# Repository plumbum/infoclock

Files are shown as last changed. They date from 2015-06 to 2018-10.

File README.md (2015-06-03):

HMI WiFi board
==============

Features
--------

  * STM32F103Cxxx MCU;
  * TFT LCD 3.2" with resistive touchscreen;
  * WiFi ESP8266 based module;
  * USB device;
  * MicroSD card slot;
  * Buzzer;
  * DHT22 themperature/humidity sensor.

Library
-------

  * [ChibiOS/RT](http://www.chibios.org/)
  * [uGFX](http://ugfx.org/)

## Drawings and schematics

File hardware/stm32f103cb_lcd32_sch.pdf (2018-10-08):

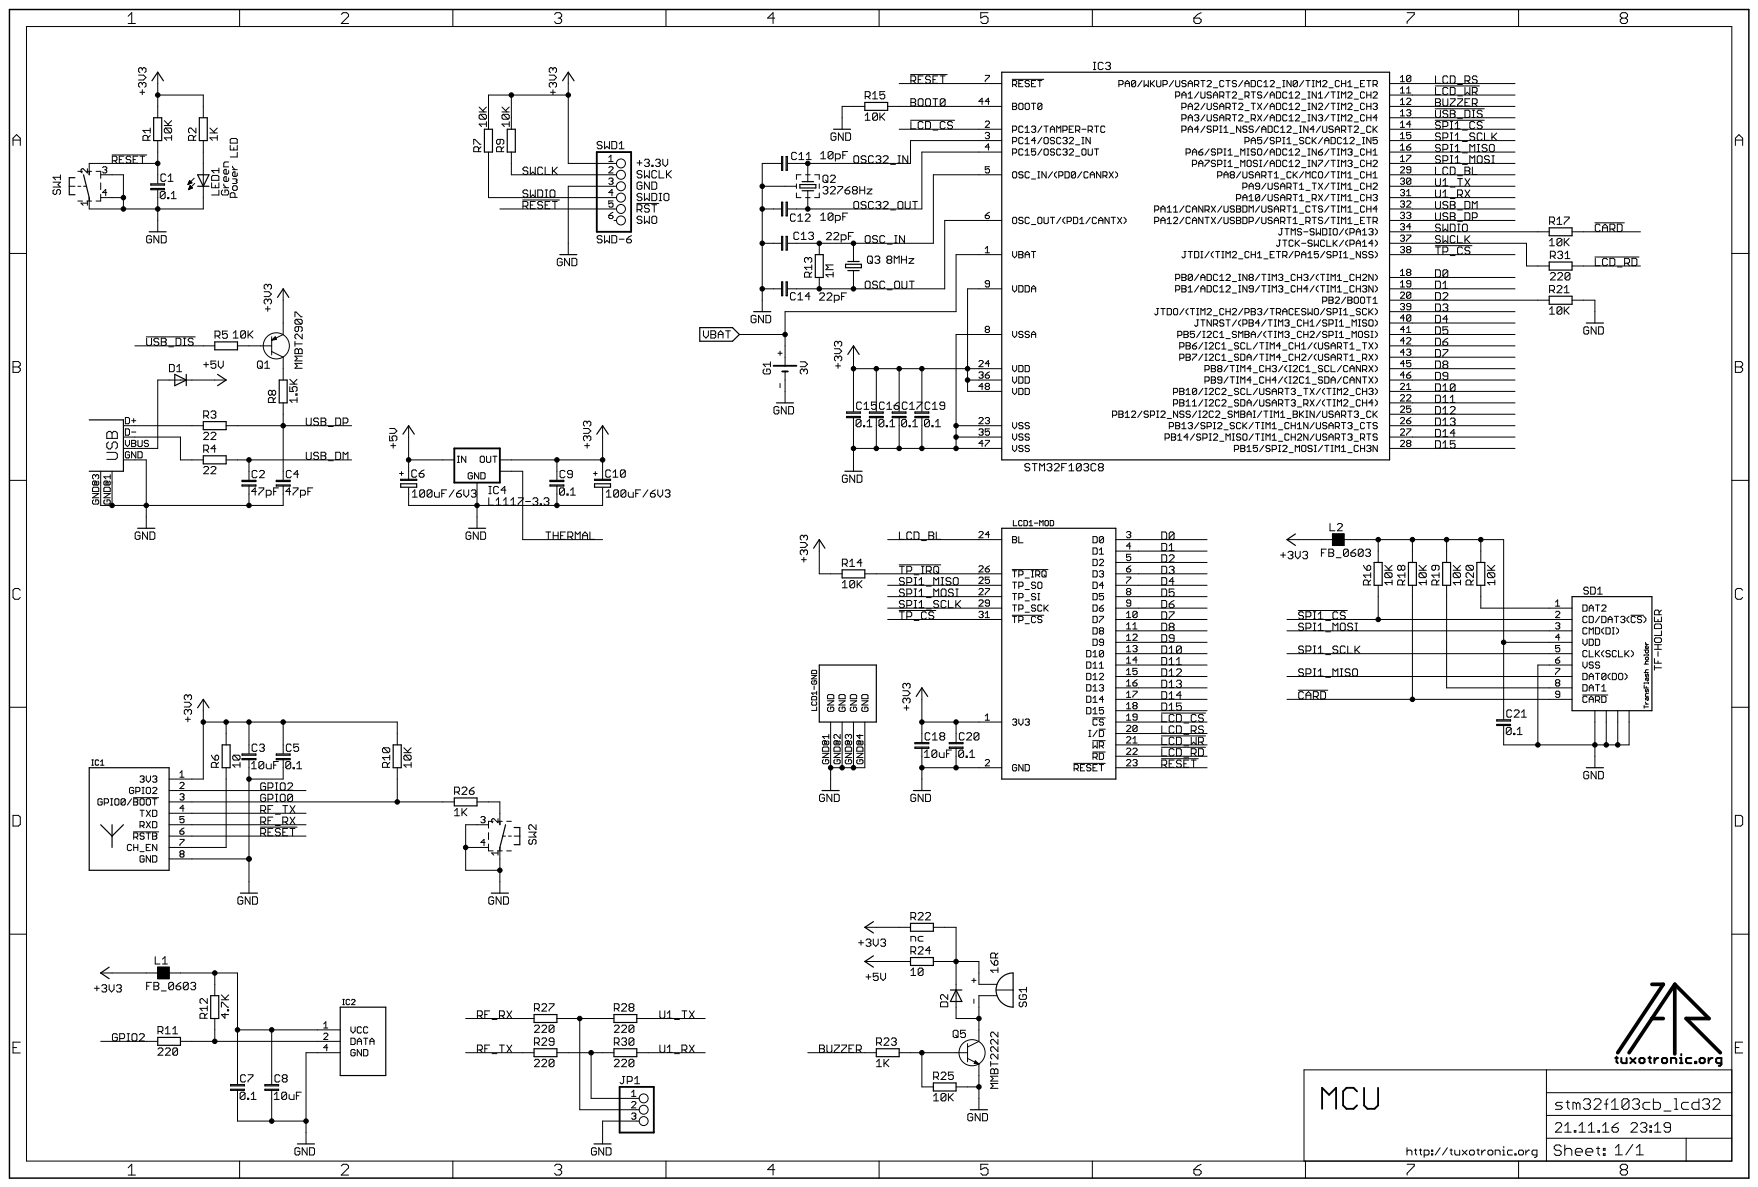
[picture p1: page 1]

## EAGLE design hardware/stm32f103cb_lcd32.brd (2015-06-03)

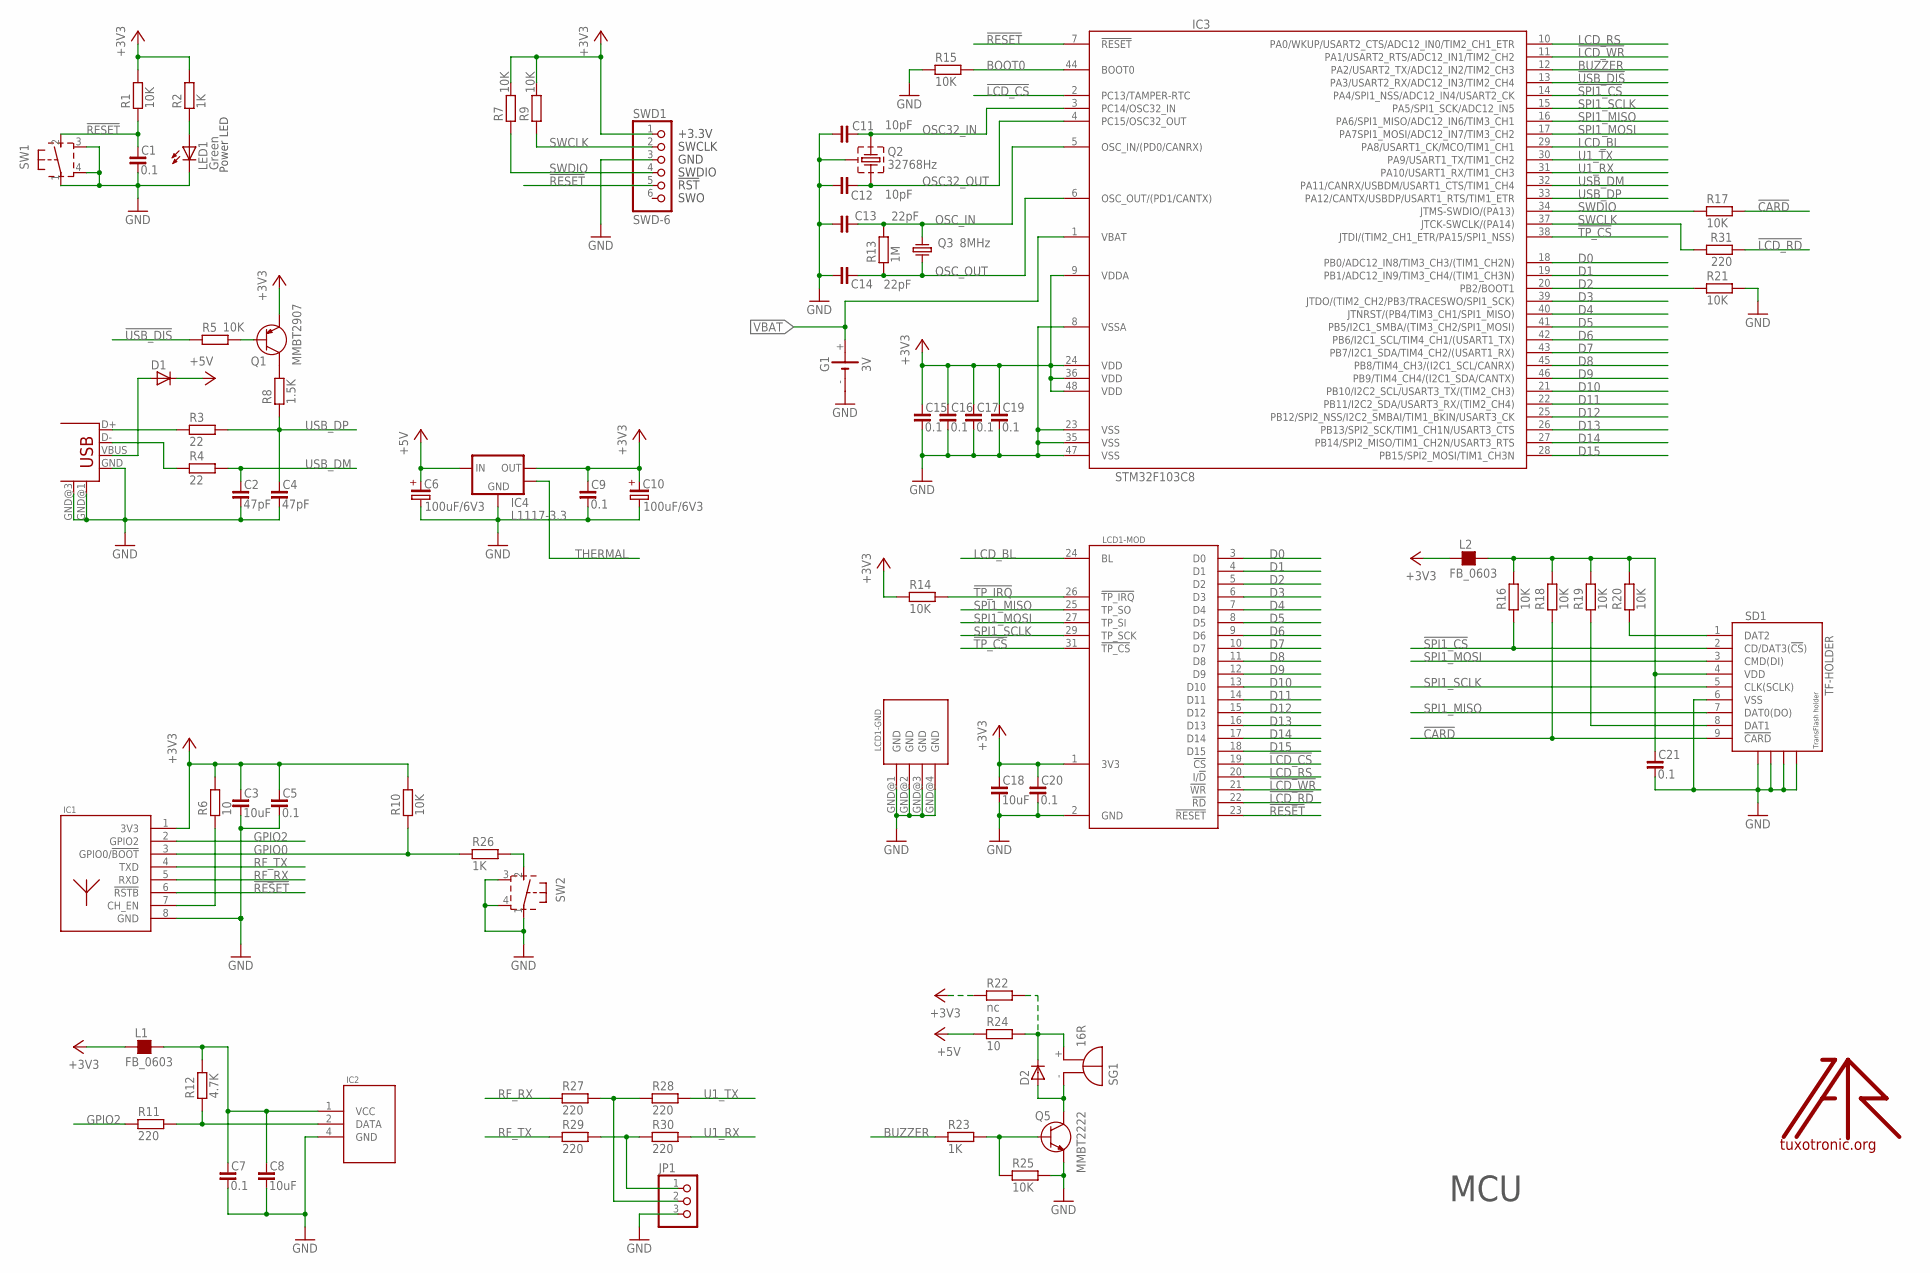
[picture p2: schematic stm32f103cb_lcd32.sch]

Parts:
C1, C5, C7, C15, C16, C17, C19, C20, C21: 0.1; C0603
C2, C4: 47pF; C0603
C3, C8, C18: 10uF; C0805
C6, C10: 100uF/6V3; SMC_D
C9: 0.1; C0805
C11, C12: 10pF; C0603
C13, C14: 22pF; C0603
D1: D-SMB; SMB
D2: D-SOD-80; SOD80
G1: 3V; SMT1220
IC1: ESP-11; ESP11
IC2: DHT22; DHT
IC3: STM32F103C8; LQFP48
IC4: L1117-3.3; SOT223-THP
JP1: PINHD-1X3_2.54S; 1X03SMALL
L1, L2: FB_0603; L0603
LCD1: YX32B
LED1: Green; CHIP-LED0805
LOGO1: LOGO; TT_LOGO
Q1: MMBT2907; SOT23
Q2: 32768Hz; TC38H-G
Q3: 8MHz; HC49/S
Q5: MMBT2222; SOT23
R1, R5, R7, R9, R10, R14, R15, R16, R17, R18, R19, R20, R21, R25: 10K; R0603
R2, R23, R26: 1K; R0603
R3, R4: 22; R0603
R6, R24: 10; R0603
R8: 1.5K; R0603
R11, R27, R28, R29, R30, R31: 220; R0603
R12: 4.7K; R0603
R13: 1M; R0603
R22: nc; R0603
SD1: TF-HOLDER; TF-PULL
SG1: 16R; F/QMBIII
SW1, SW2: 31-XX; B3F-31XX
SWD1: SWD-6; JTAG6PIN
USB1: USB-MB-S

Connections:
!CARD: R17.2, R18.1, SD1.9 (!CARD)
!LCD_CS: IC3.2 (PC13/TAMPER-RTC), LCD1.19 (!CS)
!LCD_RD: LCD1.22 (!RD), R31.1
!LCD_WR: IC3.11 (PA1/USART2_RTS/ADC12_IN1/TIM2_CH2), LCD1.21 (!WR)
!RESET: C1.1, IC1.6 (!RSTB), IC3.7 (!RESET), LCD1.23 (!RESET), R1.1, SW1.2 (S), SWD1.5
!SPI1_CS: IC3.14 (PA4/SPI1_NSS/ADC12_IN4/USART2_CK), R16.1, SD1.2 (CD/DAT3(!CS!))
!TP_CS: IC3.38 (JTDI/(TIM2_CH1_ETR/PA15/SPI1_NSS)), LCD1.31 (!TP_CS)
!TP_IRQ: LCD1.26 (!TP_IRQ), R14.2
!USB_DIS: IC3.13 (PA3/USART2_RX/ADC12_IN3/TIM2_CH4), R5.1
+3V3: C3.1, C5.1, C9.1, C10.+, C15.1, C16.1, C17.1, C18.1, C19.1, C20.1, IC1.1 (3V3), IC3.9 (VDDA), IC3.24 (VDD), IC3.36 (VDD), IC3.48 (VDD), IC4.2 (OUT), L1.1, L2.1, LCD1.1 (3V3), Q1.2 (E), R1.2, R2.2, R6.2, R7.2, R9.2, R10.2, R14.1, R22.1, SWD1.1
+5V: C6.+, D1.1 (C), IC4.3 (IN), R24.1
BOOT0: IC3.44 (BOOT0), R15.2
BUZZER: IC3.12 (PA2/USART2_TX/ADC12_IN2/TIM2_CH3), R23.1
D0: IC3.18 (PB0/ADC12_IN8/TIM3_CH3/(TIM1_CH2N)), LCD1.3 (D0)
D1: IC3.19 (PB1/ADC12_IN9/TIM3_CH4/(TIM1_CH3N)), LCD1.4 (D1)
D2: IC3.20 (PB2/BOOT1), LCD1.5 (D2), R21.1
D3: IC3.39 (JTDO/(TIM2_CH2/PB3/TRACESWO/SPI1_SCK)), LCD1.6 (D3)
D4: IC3.40 (JTNRST/(PB4/TIM3_CH1/SPI1_MISO)), LCD1.7 (D4)
D5: IC3.41 (PB5/I2C1_SMBA/(TIM3_CH2/SPI1_MOSI)), LCD1.8 (D5)
D6: IC3.42 (PB6/I2C1_SCL/TIM4_CH1/(USART1_TX)), LCD1.9 (D6)
D7: IC3.43 (PB7/I2C1_SDA/TIM4_CH2/(USART1_RX)), LCD1.10 (D7)
D8: IC3.45 (PB8/TIM4_CH3/(I2C1_SCL/CANRX)), LCD1.11 (D8)
D9: IC3.46 (PB9/TIM4_CH4/(I2C1_SDA/CANTX)), LCD1.12 (D9)
D10: IC3.21 (PB10/I2C2_SCL/USART3_TX/(TIM2_CH3)), LCD1.13 (D10)
D11: IC3.22 (PB11/I2C2_SDA/USART3_RX/(TIM2_CH4)), LCD1.14 (D11)
D12: IC3.25 (PB12/SPI2_NSS/I2C2_SMBAI/TIM1_BKIN/USAR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), LCD1.15 (D12)
D13: IC3.26 (PB13/SPI2_SCK/TIM1_CH1N/USART3_CTS), LCD1.16 (D13)
D14: IC3.27 (PB14/SPI2_MISO/TIM1_CH2N/USART3_RTS), LCD1.17 (D14)
D15: IC3.28 (PB15/SPI2_MOSI/TIM1_CH3N), LCD1.18 (D15)
GND: C1.2, C2.2, C3.2, C4.2, C5.2, C6.-, C7.2, C8.2, C9.2, C10.-, C11.2, C12.2, C13.2, C14.2, C15.2, C16.2, C17.2, C18.2, C19.2, C20.2, C21.2, G1.-, IC1.8 (GND), IC2.4 (GND), IC3.8 (VSSA), IC3.23 (VSS), IC3.35 (VSS), IC3.47 (VSS), IC4.1 (GND), JP1.3, LCD1.2 (GND), LCD1.GND@1 (GND), LCD1.GND@2 (GND), LCD1.GND@3 (GND), LCD1.GND@4 (GND), LED1.C, Q2.GND, Q5.2 (E), R15.1, R21.2, R25.2, SD1.6 (VSS), SD1.S1, SD1.S2, SD1.S3, SD1.S4, SW1.1, SW1.3 (GND1), SW1.4 (GND2), SW2.1, SW2.3 (GND1), SW2.4 (GND2), SWD1.3, USB1.GND, USB1.GND@1 (GND), USB1.GND@3 (GND)
GPIO0: IC1.3 (GPIO0/!BOOT), R10.1, R26.1
GPIO2: IC1.2 (GPIO2), R11.1
LCD_BL: IC3.29 (PA8/USART1_CK/MCO/TIM1_CH1), LCD1.24 (BL)
LCD_RS: IC3.10 (PA0/WKUP/USART2_CTS/ADC12_IN0/TIM2_CH1_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), LCD1.20 (I/!D)
unnamed: Q1.3 (C), R8.2
unnamed: D1.2 (A), USB1.VBUS
unnamed: LED1.A, R2.1
unnamed: Q5.1 (B), R23.2, R25.1
unnamed: IC1.7 (CH_EN), R6.1
unnamed: IC2.2 (DATA), R11.2, R12.1
unnamed: C21.1, L2.2, R16.2, R18.2, R19.2, R20.2, SD1.4 (VDD)
unnamed: R20.1, SD1.1 (DAT2)
unnamed: R19.1, SD1.8 (DAT1)
unnamed: R3.1, USB1.D+
unnamed: C7.1, C8.1, IC2.1 (VCC), L1.2, R12.2
unnamed: D2.2 (A), Q5.3 (C), SG1.- (+)
unnamed: D2.1 (C), R22.2, R24.2, SG1.+ (-)
unnamed: R26.2, SW2.2 (S)
unnamed: JP1.1, R29.2, R30.1
unnamed: JP1.2, R27.2, R28.1
unnamed: R4.1, USB1.D-
unnamed: Q1.1 (B), R5.2
OSC32_IN: C11.1, IC3.3 (PC14/OSC32_IN), Q2.2
OSC32_OUT: C12.1, IC3.4 (PC15/OSC32_OUT), Q2.1
OSC_IN: C13.1, IC3.5 (OSC_IN/(PD0/CANRX)), Q3.1, R13.2
OSC_OUT: C14.1, IC3.6 (OSC_OUT/(PD1/CANTX)), Q3.2, R13.1
RF_RX: IC1.5 (RXD), R27.1
RF_TX: IC1.4 (TXD), R29.1
SPI1_MISO: IC3.16 (PA6/SPI1_MISO/ADC12_IN6/TIM3_CH1), LCD1.25 (TP_SO), SD1.7 (DAT0(DO))
SPI1_MOSI: IC3.17 (PA7SPI1_MOSI/ADC12_IN7/TIM3_CH2), LCD1.27 (TP_SI), SD1.3 (CMD(DI))
SPI1_SCLK: IC3.15 (PA5/SPI1_SCK/ADC12_IN5), LCD1.29 (TP_SCK), SD1.5 (CLK(SCLK))
SWCLK: IC3.37 (JTCK-SWCLK/(PA14)), R9.1, R31.2, SWD1.2
SWDIO: IC3.34 (JTMS-SWDIO/(PA13)), R7.1, R17.1, SWD1.4
THERMAL: IC4.4 (MASS)
U1_RX: IC3.31 (PA10/USART1_RX/TIM1_CH3), R30.2
U1_TX: IC3.30 (PA9/USART1_TX/TIM1_CH2), R28.2
USB_DM: C2.1, IC3.32 (PA11/CANRX/USBDM/USART1_CTS/TIM1_CH4), R4.2
USB_DP: C4.1, IC3.33 (PA12/CANTX/USBDP/USART1_RTS/TIM1_ETR), R3.2, R8.1
VBAT: G1.+, IC3.1 (VBAT)

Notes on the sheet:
MCU
Power LED

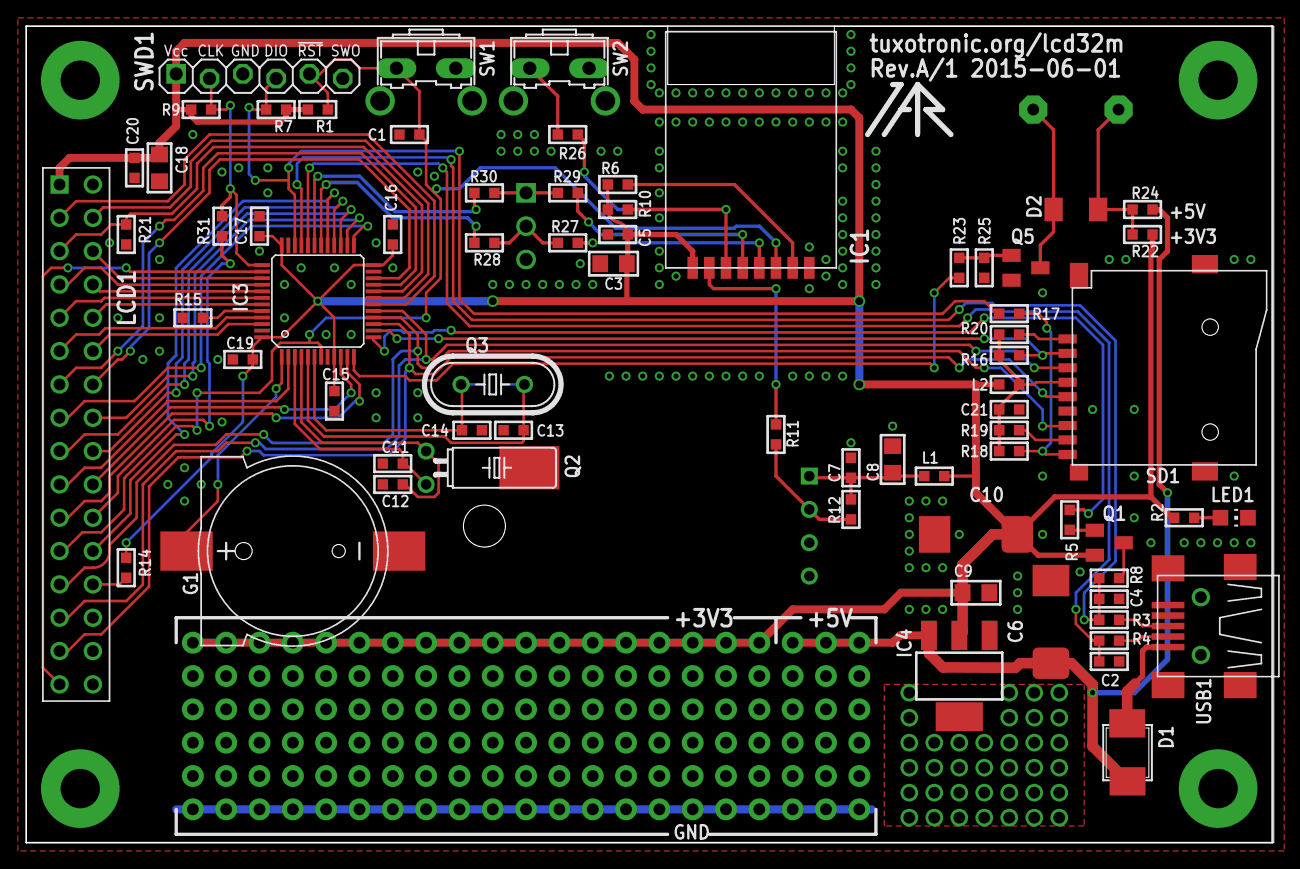
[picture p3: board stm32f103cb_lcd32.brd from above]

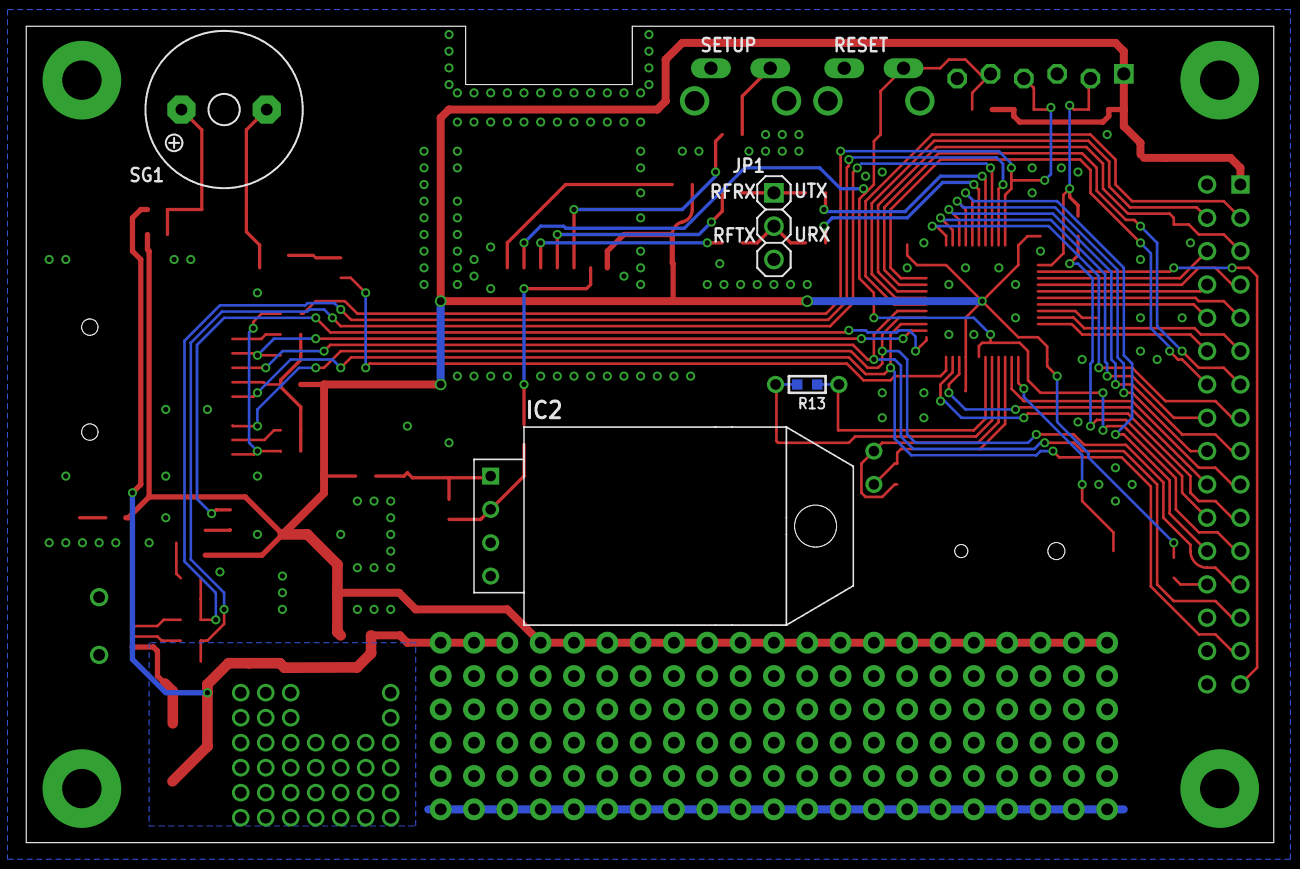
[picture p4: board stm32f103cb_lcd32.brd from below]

Board: 2 copper layers, 95.1 x 62.2 mm, 75 parts (4 on the bottom side), 68 nets.

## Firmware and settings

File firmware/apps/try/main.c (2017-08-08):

/*
    ChibiOS/RT - Copyright (C) 2006-2013 Giovanni Di Sirio

    Licensed under the Apache License, Version 2.0 (the "License");
    you may not use this file except in compliance with the License.
    You may obtain a copy of the License at

        http://www.apache.org/licenses/LICENSE-2.0

    Unless required by applicable law or agreed to in writing, software
    distributed under the License is distributed on an "AS IS" BASIS,
    WITHOUT WARRANTIES OR CONDITIONS OF ANY KIND, either express or implied.
    See the License for the specific language governing permissions and
    limitations under the License.
*/

#include <stdio.h>
#include <string.h>
#include <stdlib.h>
#include <time.h>

#include <ch.h>
#include <hal.h>

#include <chrtclib.h>
#include <shell.h>
#include <chprintf.h>

#include <myusb.h>

#include "yx32b.h"


/*===========================================================================*/
/* Command line related.                                                     */
/*===========================================================================*/

#define SHELL_WA_SIZE   THD_WA_SIZE(2048)
#define TEST_WA_SIZE    THD_WA_SIZE(256)

static void cmd_mem(BaseSequentialStream *chp, int argc, char *argv[]) {
    size_t n, size;

    (void)argv;
    if (argc > 0) {
        chprintf(chp, "Usage: mem\r\n");
        return;
    }
    n = chHeapStatus(NULL, &size);
    chprintf(chp, "core free memory : %u bytes\r\n", chCoreStatus());
    chprintf(chp, "heap fragments   : %u\r\n", n);
    chprintf(chp, "heap free total  : %u bytes\r\n", size);
}

static void cmd_threads(BaseSequentialStream *chp, int argc, char *argv[]) {
    static const char *states[] = {THD_STATE_NAMES};
    Thread *tp;

    (void)argv;
    if (argc > 0) {
        chprintf(chp, "Usage: threads\r\n");
        return;
    }
    chprintf(chp, "    addr    stack prio refs     state time\r\n");
    tp = chRegFirstThread();
    do {
        chprintf(chp, "%.8lx %.8lx %4lu %4lu %9s %lu\r\n",
                 (uint32_t)tp, (uint32_t)tp->p_ctx.r13,
                 (uint32_t)tp->p_prio, (uint32_t)(tp->p_refs - 1),
                 states[tp->p_state], (uint32_t)tp->p_time);
        tp = chRegNextThread(tp);
    } while (tp != NULL);
}

/*
static void cmd_write(BaseSequentialStream *chp, int argc, char *argv[]) {
    static uint8_t buf[] =
        "0123456789abcdef0123456789abcdef0123456789abcdef0123456789abcdef"
        "0123456789abcdef0123456789abcdef0123456789abcdef0123456789abcdef"
        "0123456789abcdef0123456789abcdef0123456789abcdef0123456789abcdef"
        "0123456789abcdef0123456789abcdef0123456789abcdef0123456789abcdef"
        "0123456789abcdef0123456789abcdef0123456789abcdef0123456789abcdef"
        "0123456789abcdef0123456789abcdef0123456789abcdef0123456789abcdef"
        "0123456789abcdef0123456789abcdef0123456789abcdef0123456789abcdef"
        "0123456789abcdef0123456789abcdef0123456789abcdef0123456789abcdef"
        "0123456789abcdef0123456789abcdef0123456789abcdef0123456789abcdef"
        "0123456789abcdef0123456789abcdef0123456789abcdef0123456789abcdef"
        "0123456789abcdef0123456789abcdef0123456789abcdef0123456789abcdef"
        "0123456789abcdef0123456789abcdef0123456789abcdef0123456789abcdef"
        "0123456789abcdef0123456789abcdef0123456789abcdef0123456789abcdef"
        "0123456789abcdef0123456789abcdef0123456789abcdef0123456789abcdef"
        "0123456789abcdef0123456789abcdef0123456789abcdef0123456789abcdef"
        "0123456789abcdef0123456789abcdef0123456789abcdef0123456789abcdef";

    (void)argv;
    if (argc > 0) {
        chprintf(chp, "Usage: write\r\n");
        return;
    }

    while (chnGetTimeout((BaseChannel *)chp, TIME_IMMEDIATE) == Q_TIMEOUT) {
        chSequentialStreamWrite(&SDU1, buf, sizeof buf - 1);
    }
    chprintf(chp, "\r\n\nstopped\r\n");
}
*/

static void cmd_lcd_init(BaseSequentialStream *chp, int argc, char *argv[]) {
    (void)argc;
    (void)argv;
    chprintf(chp, "\r\nTry to init LCD\r\n");
    uint16_t status = lcdInit();
    chprintf(chp, "LCD status 0x%04x\r\n", status);
}

static void cmd_set_utime(BaseSequentialStream *chp, int argc, char *argv[]) {
    time_t utime;
    if ((argc != 1) || (utime = atoi(argv[0])) == 0) {
        chprintf(chp, "Usage: set_utime <unix time value>\r\n");
        return;
    }
    rtcSetTimeUnixSec(&RTCD1, utime);
    chprintf(chp, "Set new time %d\r\n", utime);
}

static const ShellCommand commands[] = {
    {"mem", cmd_mem},
    {"threads", cmd_threads},
    // {"write", cmd_write},
    {"init", cmd_lcd_init},
    {"set_utime", cmd_set_utime},
    {NULL, NULL}
};

static const ShellConfig shell_cfg1 = {
    (BaseSequentialStream *)&SDU1,
    commands
};

/*===========================================================================*/
/* Generic code.                                                             */
/*===========================================================================*/

/*
 * Red LED blinker thread, times are in milliseconds.
 */
static WORKING_AREA(waThread1, 128);
static msg_t Thread1(void *arg)
{

    (void)arg;
    chRegSetThreadName("blinker");
    while (!chThdShouldTerminate()) {
        systime_t time = myusbState() == USB_ACTIVE ? 250 : 500;
        // palClearPad(IOPORT3, GPIOC_LED);
        chThdSleepMilliseconds(time);
        // palSetPad(IOPORT3, GPIOC_LED);
        chThdSleepMilliseconds(time);
    }
    return 0;
}


RTCTime timespec;
uint32_t prev_time;
char buf[128];

/*
 * Application entry point.
 */
int main(void)
{
    Thread *shelltp = NULL;

    /*
     * System initializations.
     * - HAL initialization, this also initializes the configured device drivers
     *   and performs the board-specific initializations.
     * - Kernel initialization, the main() function becomes a thread and the
     *   RTOS is active.
     */
    halInit();
    chSysInit();


    palClearPad(GPIOA, GPIOA_LCD_BL);

    sdStart(&SD1, NULL);
    // sdWrite(&SD1, "Hello world!\r\n", 14);

    myusbInit();

    /*
     * Shell manager initialization.
     */
    shellInit();

    /*
     * Creates the blinker thread.
     */
    chThdCreateStatic(waThread1, sizeof(waThread1), NORMALPRIO, Thread1, NULL);

    // chThdSleepMilliseconds(100);
    int lcdStat = lcdInit();
    if (lcdStat == 0) {
        palSetPad(GPIOA, GPIOA_LCD_BL);
    }
    lcdTest();

    /*
     * Normal main() thread activity, in this demo it does nothing except
     * sleeping in a loop and check the button state.
     */
    while (TRUE) {
        // sdWrite(&SD1, "Next line\r\n", 11);
        if (!shelltp && (SDU1.config->usbp->state == USB_ACTIVE))
            shelltp = shellCreate(&shell_cfg1, SHELL_WA_SIZE, NORMALPRIO);
        else if (chThdTerminated(shelltp)) {
            chThdRelease(shelltp);    /* Recovers memory of the previous shell.   */
            shelltp = NULL;           /* Triggers spawning of a new shell.        */
        }

        rtcGetTime(&RTCD1, &timespec);
        if (prev_time != timespec.tv_sec) {
            prev_time = timespec.tv_sec;
            chsnprintf(buf, sizeof(buf), "%10d", timespec.tv_sec);
            lcdStr(20, 20, buf, COLOR_RED, COLOR_BLACK);
            struct tm tim;
            rtcGetTimeTm(&RTCD1, &tim);
            chsnprintf(buf, sizeof(buf), "%04d/%02d/%02d %02d:%02d:%02d",
                tim.tm_year + 1900,
                tim.tm_mon + 1,
                tim.tm_mday,
                tim.tm_hour,
                tim.tm_min,
                tim.tm_sec
            );
            lcdStr(20, 28, buf, COLOR_GREEN, COLOR_BLACK);
        }
        chThdSleepMilliseconds(50);
    }
}

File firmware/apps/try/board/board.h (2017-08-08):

/*
    ChibiOS/RT - Copyright (C) 2006-2013 Giovanni Di Sirio

    Licensed under the Apache License, Version 2.0 (the "License");
    you may not use this file except in compliance with the License.
    You may obtain a copy of the License at

        http://www.apache.org/licenses/LICENSE-2.0

    Unless required by applicable law or agreed to in writing, software
    distributed under the License is distributed on an "AS IS" BASIS,
    WITHOUT WARRANTIES OR CONDITIONS OF ANY KIND, either express or implied.
    See the License for the specific language governing permissions and
    limitations under the License.
*/

#ifndef _BOARD_H_
#define _BOARD_H_

/*
 * Setup for the Olimex STM33-H103 proto board.
 */

/*
 * Board identifier.
 */
#define BOARD_HMI_EASY
#define BOARD_NAME              "HMI easy controller"

/*
 * Board frequencies.
 */
#define STM32_LSECLK            32768
#define STM32_HSECLK            8000000

/*
 * MCU type, supported types are defined in ./os/hal/platforms/hal_lld.h.
 */
#define STM32F10X_MD

/*
 * IO pins assignments.
 */
#define GPIOC_LCD_CS            13
#define GPIOA_LCD_RS            0
#define GPIOA_LCD_WR            1
#define GPIOA_LCD_RD            2
#define GPIOA_USB_DISC          3
#define GPIOA_SPI1_CS           4
#define GPIOA_SPI1_SCLK         5
#define GPIOA_SPI1_MISO         6
#define GPIOA_SPI1_MOSI         7
#define GPIOA_LCD_BL            8
#define GPIOA_U1_TX             9
#define GPIOA_U1_RX             10
#define GPIOA_TP_CS             15

/*
 * I/O ports initial setup, this configuration is established soon after reset
 * in the initialization code.
 *
 * The digits have the following meaning:
 *   0 - Analog input.
 *   1 - Push Pull output 10MHz.
 *   2 - Push Pull output 2MHz.
 *   3 - Push Pull output 50MHz.
 *   4 - Digital input.
 *   5 - Open Drain output 10MHz.
 *   6 - Open Drain output 2MHz.
 *   7 - Open Drain output 50MHz.
 *   8 - Digital input with PullUp or PullDown resistor depending on ODR.
 *   9 - Alternate Push Pull output 10MHz.
 *   A - Alternate Push Pull output 2MHz.
 *   B - Alternate Push Pull output 50MHz.
 *   C - Reserved.
 *   D - Alternate Open Drain output 10MHz.
 *   E - Alternate Open Drain output 2MHz.
 *   F - Alternate Open Drain output 50MHz.
 * Please refer to the STM32 Reference Manual for details.
 */

/*
 * Port A setup.
 * Everything input with pull-up except:
 * PA0  - PP                (LCD_RS)
 * PA1  - PP                (#LCD_WR)
 * PA2  - PP                (#LCD_RD)
 * PA3  - PP                (#USB_DIS)
 * PA4  - PP                (#SPI1_CS)
 * PA5  - Alternate output  (SPI1_SCLK)
 * PA6  - Alternate input   (SPI1_MISO)
 * PA7  - Alternate output  (SPI1_MOSI)
 * PA8  - PP                (LCD_BL)
 * PA9  - Alternate output  (USART1 TX).
 * PA10 - Normal input      (USART1 RX).
 * PA15 - PP                (#TP_CS)
 */
#define VAL_GPIOACRL            0xB8B33333      /*  PA7...PA0 */
#define VAL_GPIOACRH            0x388888B3      /* PA15...PA8 */
#define VAL_GPIOAODR            0xFFFFFFFF

/*
 * Port B setup.
 * Everything input with pull-up except:
 * PB0-PB15 - PP (Display D0-D15)
 */
#define VAL_GPIOBCRL            0x88888888      /*  PB7...PB0 */
#define VAL_GPIOBCRH            0x88888888      /* PB15...PB8 */
#define VAL_GPIOBODR            0xFFFFFFFF

/*
 * Port C setup.
 * Everything input with pull-up except:
 * PC13 - Push Pull output (#LCD_CS).
 */
#define VAL_GPIOCCRL            0x88888888      /*  PC7...PC0 */
#define VAL_GPIOCCRH            0x88388888      /* PC15...PC8 */
#define VAL_GPIOCODR            0xFFFFFFFF

/*
 * Port D setup.
 * Everything input with pull-up except:
 * PD0  - Normal input (XTAL).
 * PD1  - Normal input (XTAL).
 */
#define VAL_GPIODCRL            0x88888844      /*  PD7...PD0 */
#define VAL_GPIODCRH            0x88888888      /* PD15...PD8 */
#define VAL_GPIODODR            0xFFFFFFFF

/*
 * Port E setup.
 * Everything input with pull-up except:
 */
#define VAL_GPIOECRL            0x88888888      /*  PE7...PE0 */
#define VAL_GPIOECRH            0x88888888      /* PE15...PE8 */
#define VAL_GPIOEODR            0xFFFFFFFF

/*
 * USB bus activation macro, required by the USB driver.
 */
#define usb_lld_connect_bus(usbp) palClearPad(GPIOA, GPIOA_USB_DISC)

/*
 * USB bus de-activation macro, required by the USB driver.
 */
#define usb_lld_disconnect_bus(usbp) palSetPad(GPIOA, GPIOA_USB_DISC)


#if !defined(_FROM_ASM_)
#ifdef __cplusplus
extern "C" {
#endif
  void boardInit(void);
#ifdef __cplusplus
}
#endif
#endif /* _FROM_ASM_ */

#endif /* _BOARD_H_ */

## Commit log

2015-06-03 Control board (copy from https://bitbucket.org/plumbum/ttgui)
    [stm32f103cb_lcd32.brd, stm32f103cb_lcd32.sch]
2015-06-03 Ignore eagle cad and vim files
2015-06-03 Test board application
2015-06-03 Element values
    [stm32f103cb_lcd32.brd, stm32f103cb_lcd32.sch]
2015-06-04 schematic & pcb in hardware directory
    [stm32f103cb_lcd32.brd, stm32f103cb_lcd32.sch]
2015-06-04 pin descriptions
2017-08-08 board configuration fixes
2017-12-05 try print fonts
2018-10-08 schematic in pdf

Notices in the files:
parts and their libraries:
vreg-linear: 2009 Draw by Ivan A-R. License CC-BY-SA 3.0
